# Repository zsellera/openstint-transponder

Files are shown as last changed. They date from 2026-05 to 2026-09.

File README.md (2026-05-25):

# OpenStint transponder reference design, version 2

RC (surface) racing transponder with ATtiny816/1616/3216, featuring:
* OpenStint protocol reference implentation (this is not an RC3 clone!)
* 5 MHz BPSK using SPI MOSI (UART module can send SPI without transmit gaps)
* A two-transistor push-pull coil driver
* Signal level is circa the same as of an RC4
* Works down to 2.8V, output level remains flat down to 3.4V (MiniZ/1S support)
* Reverse polarity protection
* Power line filtering
* LCSC product codes added (orderable from JLCPCB)

**Related projects:** [OpenStint decoder](https://github.com/zsellera/openstint) | [Loop Amplifier](https://github.com/zsellera/openstint-preamp)

JLCPCB manifactures and assembles 5 panels of 2x4s, grand total of 40 pcs, for less than $200, including taxes and shipping (Hungary 27% VAT, no tariff, 2026 May).

openstint transponder v2

**Signal level**

Blue: RC4Hybrid, yellow: OpenStint v2 (antenna is the same distance from the detector)
OpenStint transponder to RC4H comparision

**Radio performance**
SpikeImage0022

## Old version

There is a previous version, with lower output level, more stressed components, pickier power requirements, using an STM32 MCU. It's on [v1](https://github.com/zsellera/openstint-transponder/tree/v1) branch. Production files from [2025 December](https://github.com/zsellera/openstint-transponder/releases/tag/release-2025-12-10).

## Manufacting

See [relases](https://github.com/zsellera/openstint-transponder/releases/tag/nightly-master) for gerber, pos and BOM files. These are directly uploadable to [JLCPCB](https://jlcpcb.com/).

[Order placement guide](https://www.rctech.net/forum/showpost.php?p=16260447&postcount=66)

Order a standard 1.2 mm 4-layer PCB to get the same performace as tested.

```
kikit panelize \
    --layout 'hspace: 3mm; vspace: 3mm; rows: 4; cols: 2' \
    --tabs 'type: fixed; vwidth: 4mm; hwidth: 4mm; vcount: 0' \
    --cuts 'type: mousebites; offset: -0.25mm' \
    --framing 'type: frame; hspace: 3mm; vspace: 3mm; width: 4mm' \
    --post 'millradius: 1.5mm' \
    ...
```

```
kikit fab jlcpcb --assembly --schematic ./openstint-transponder.kicad_sch ./panel/panel-8.kicad_pcb panel/
```

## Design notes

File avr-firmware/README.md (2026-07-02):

# AVR Firmware

Firmware for the OpenStint transponder, targeting the **ATtiny816**/**ATtiny1616**/**ATtiny3216**.

Not tested with 416, but I think it would work there as well. Not measured, but I guesstimate the stack size upper limit to be around 80-90 bytes.

## Precompiled firmware

An automated job compiles the firmware, check out [releases](https://github.com/zsellera/openstint-transponder/releases/tag/nightly-master).

## Prerequisites

- `avr-gcc` toolchain (avr-gcc, avr-objcopy, avr-size)
- `avrdude` for flashing
- **Microchip ATtiny Device Family Pack (DFP)** — required because avr-libc does not ship full support for newer ATtiny 0/1/2-series chips

## Building

The project generates a Makefile with CMake, downloading AVR support packages meanwhile.

```sh
mkdir build
cd build
cmake ..
make
```

Alternatives:

```sh
# v1 revision (led on different pin)
cmake -B build -DHW_REV=v1

# manual DFP path
cmake -B build -DATTINY_DFP=/path/to/Atmel.ATtiny_DFP.2.0.368

# use "adafruit high voltage programmer"
cmake -B build -DPROGRAMMER=serialupdi
```

### Obtaining the ATtiny DFP manually

The new CMake script downloads this automatically

The DFP provides the device-specific headers, linker scripts, and startup objects needed by avr-gcc.

1. Go to the Microchip Packs Repository: <http://packs.download.atmel.com/>
2. Search for **ATtiny** and download the latest **Atmel ATtiny Series Device Support** pack (e.g. `Atmel.ATtiny_DFP.2.0.368.atpack`)
3. The `.atpack` file is a regular ZIP archive — extract it to a directory of your choice:
   ```sh
   unzip Atmel.ATtiny_DFP.2.0.368.atpack -d Atmel.ATtiny_DFP.2.0.368
   ```

The extracted directory structure contains:
```
Atmel.ATtiny_DFP.2.0.368/
  gcc/dev/attiny816/   -- linker scripts and startup objects (-B path)
  gcc/dev/attiny1616/   -- linker scripts and startup objects (-B path)
  include/              -- device header files (-I path)
```

## Flashing

```sh
make flash
```

This uses `avrdude` with an Atmel-ICE programmer over UPDI.

## Fuse Programming

FOR PAST/FUTURE REFERENCE ONLY, THIS STEP IS NOT REQUIRED!

ATtinys have an internal oscillator, which - by default - run at 16 MHz. A fuse programming
is required to make it 20 MHz. However it's pointless - the RC oscillator is so unprecise we can not calibratie it to be within 5 MHz ±19 kHz reliably (which is needed for openstint decoder to detect it).

To set the main oscillator to 20 MHz:

```sh
make fuse
```

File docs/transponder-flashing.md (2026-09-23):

---
title: Flashing OpenStint Transponder Firmware
description: How to flash the ATtiny-based OpenStint RC lap timing transponder firmware using an Atmel-ICE or a cheap UPDI programmer.
---

# Flashing the firmware

There is an automated job that compiles the firmware, check out [releases](https://github.com/zsellera/openstint-transponder/releases/tag/nightly-master). You'll need the `.hex` file. You can [compile yourself](https://github.com/zsellera/openstint-transponder/blob/master/avr-firmware/README.md), of course.

To flash the firmware, I use an [ATMEL-ICE](https://www.microchip.com/en-us/development-tool/atatmel-ice), sourceable from Mouser/DigiKey/etc. (~$100).

A much cheaper alternative is [Adafruit High Voltage UPDI Friend - USB Serial UPDI Programmer](https://www.adafruit.com/product/5893) (~$10).

## Hardware

There are test points on the bottom of the transponder:
* **VDD** powers the LDO, apply 4+ V here
* **VTG** is a testpoint to check the LDO output voltage (should be 3.3V)
* **GND**
* **UPDI** is the programming pin

You can connect +3.3V directly to `VTG`, as the LDO has reverse current protection, and not use `VDD` (leave floating).

The v2 transponder's test point spacing is 2.54 mm / 0.1" away from each other. You need pogo pins to make proper contact. [Adafruit](https://www.adafruit.com/product/5381), [AliExpress](https://www.aliexpress.com/item/4000452882780.html).

## Software

I use [avrdude](https://github.com/avrdudes/avrdude/), the makescript use it as well.

Program both the fuses and the flash memory! The fuses are set to use the 20 MHz internal RC oscillator as a fallback if the crystal oscillator fails, as a fallback mechanism.

This does both:
```
make flash
```

OR:
```
avrdude -c serialupdi -p attiny816 -U "flash:w:main.hex" -U fuse1:w:0x02:m
```

## Reading the transponder ID

The transponder ID is not stored anywhere: the firmware calculates it at boot from the chip's factory serial number (`crc32(SIGROW.SERNUM0..9) % 10000000`). The serial number is readable over UPDI, so [tools/transponder_id.py](https://github.com/zsellera/openstint-transponder/blob/master/tools/transponder_id.py) can tell you the ID a board will transmit, over the same connection you flash with. No decoder or RF power-up needed. It is read-only and works on a blank chip too.

It needs Python 3 and avrdude 7.x or newer (for the `sernum` memory), with a `serialupdi` programmer:

```
$ python tools/transponder_id.py --port COM5
SERNUM : 2F510C111E4277A305BB
ID     : 4729780
```

When building a batch, add `--csv` and `--label` to collect a labelling list as you go. Each run appends a `timestamp;label;sernum;transponder_id` row:

```
python tools/transponder_id.py --port COM5 --csv transponders.csv --label 07
```

Run `python tools/transponder_id.py --help` for the rest of the options (`--baud`, `--part`, `--avrdude`).

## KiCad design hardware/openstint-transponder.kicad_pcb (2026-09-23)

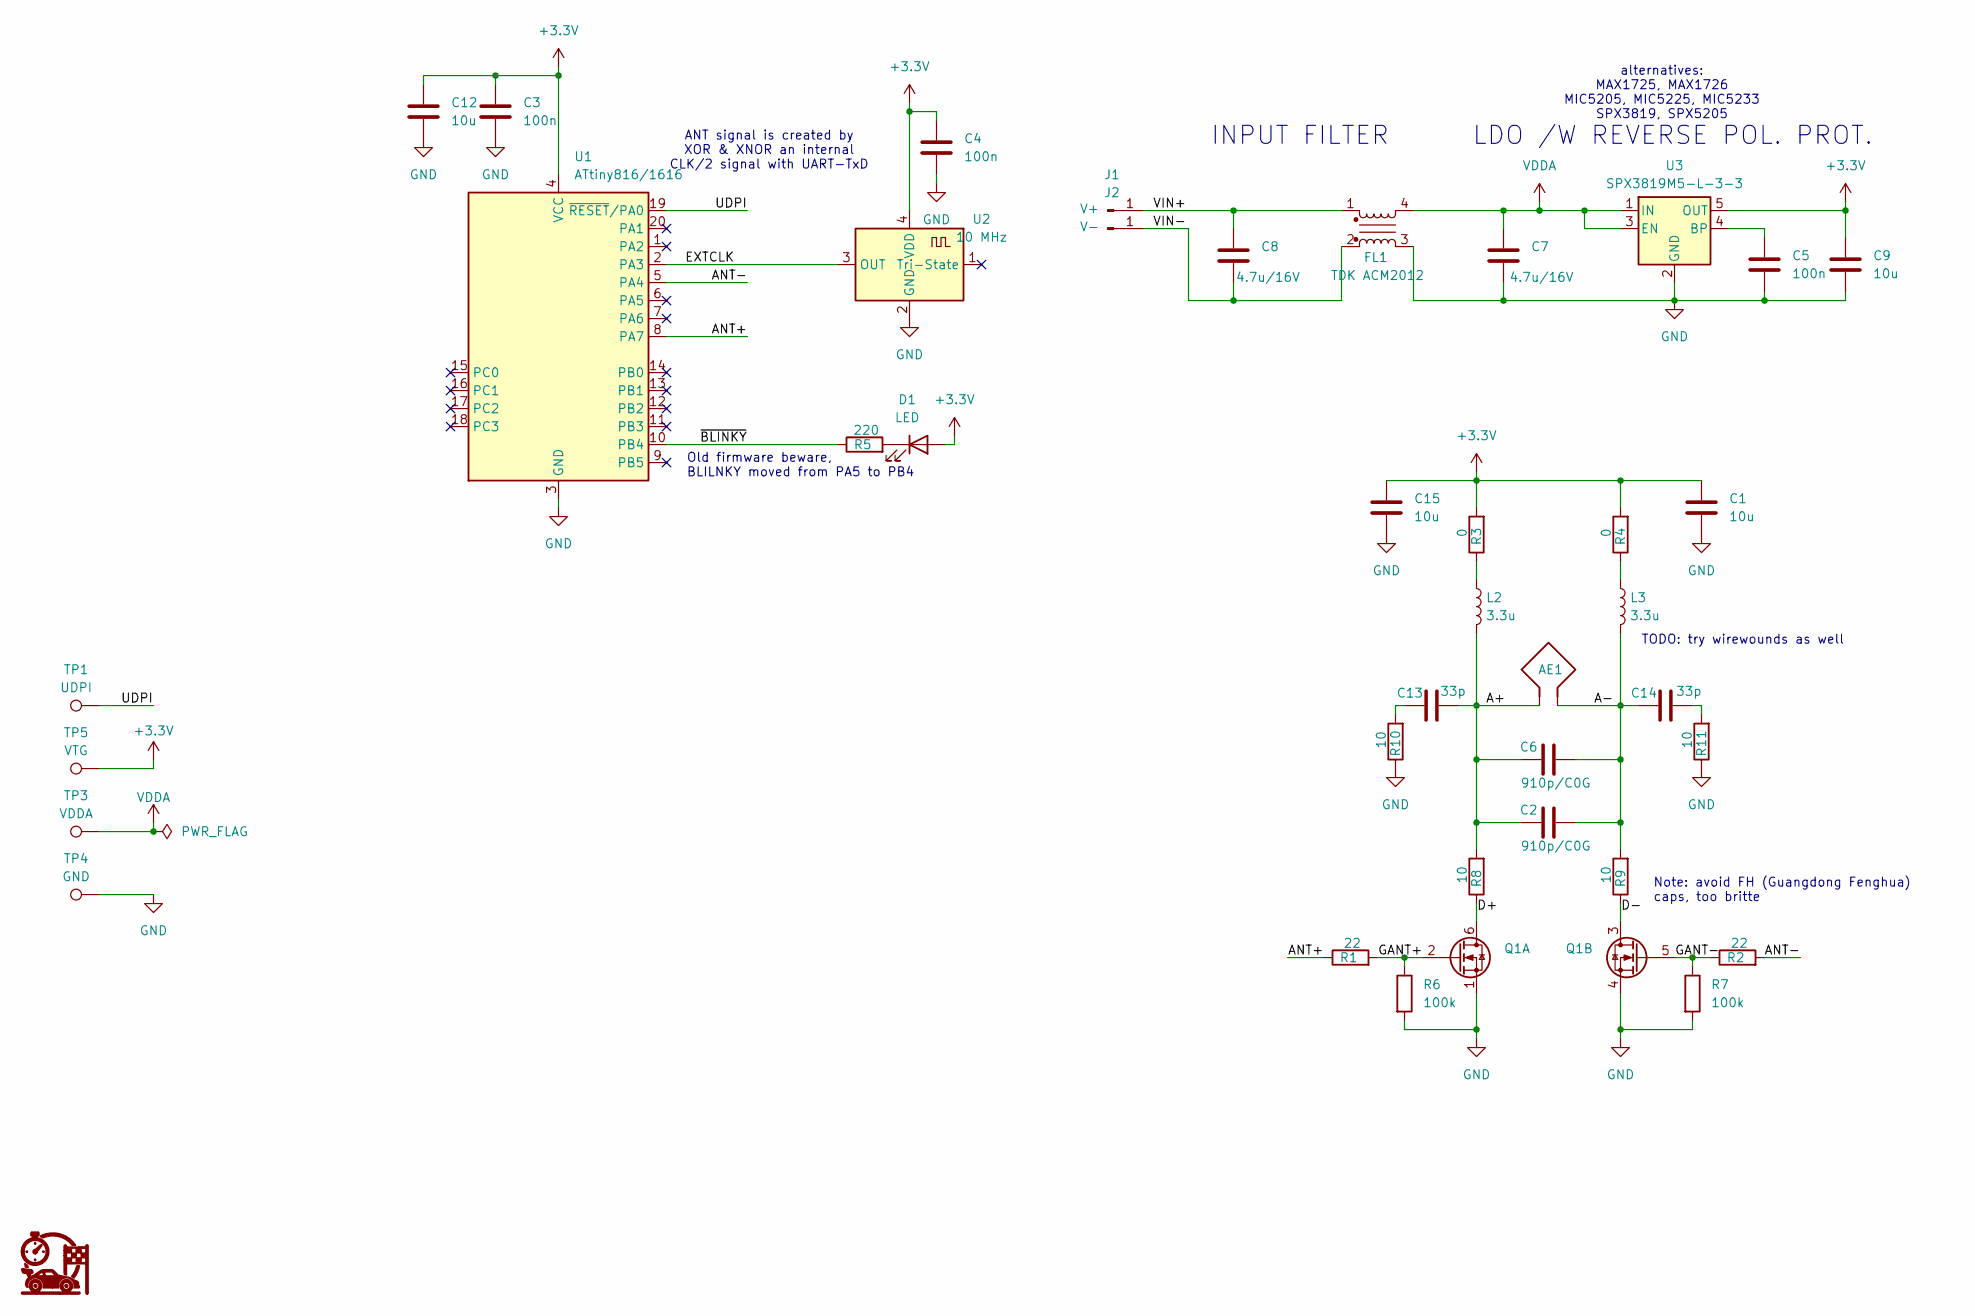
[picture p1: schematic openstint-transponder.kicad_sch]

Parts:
AE1: Antenna_Loop
C1, C9, C12, C15: 10u; C_0402_1005Metric; LCSC C15525
C2, C6: 910p/C0G; C_0402_1005Metric; LCSC C2941944
C3, C4, C5: 100n; C_0402_1005Metric; LCSC C1525
C7, C8: 4.7u/16V; C_0603_1608Metric; LCSC C19666
C13, C14: 33p; C_0402_1005Metric; LCSC C1562
D1: LED; LED_0603_1608Metric; LCSC C2286
FL1: TDK ACM2012; ACM2012; LCSC C76571
G1: SYM_OpenStint; openstint-logo_12x12
J1: V+; SolderWirePad_1x01_SMD_1x2mm
J2: V-; SolderWirePad_1x01_SMD_1x2mm
L2, L3: 3.3u; L_0603_1608Metric; LCSC C162581
Q1: PMGD280UN; SOT-363_SC-70-6; LCSC C135817
R1, R2: 22; R_0402_1005Metric; LCSC C25092
R3, R4: 0; R_0402_1005Metric; LCSC C17168
R5: 220; R_0402_1005Metric; LCSC C25091
R6, R7: 100k; R_0402_1005Metric; LCSC C25741
R8, R9, R10, R11: 10; R_0402_1005Metric; LCSC C25077
TP1: UDPI; TestPoint_Pad_D1.0mm
TP3: VDDA; TestPoint_Pad_D1.0mm
TP4: GND; TestPoint_Pad_D1.0mm
TP5: VTG; TestPoint_Pad_D1.0mm
U1: ATtiny816/1616; VQFN-20-1EP_3x3mm_P0.4mm_EP1.7x1.7mm; LCSC C2052778
U2: 10 MHz; Crystal_SMD_3225-4Pin_3.2x2.5mm; LCSC C2831380
U3: SPX3819M5-L-3-3; SOT-23-5; LCSC C9055

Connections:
+3.3V: C1.1, C3.2, C4.2, C9.1, C12.1, C15.1, D1.2 (A), R3.2, R4.2, TP5.1, U1.4 (VCC), U2.4 (VDD), U3.5 (OUT)
/A+: AE1.1, C2.1, C6.1, C13.2, L2.2, R8.2
/A-: AE1.2, C2.2, C6.2, C14.1, L3.2, R9.2
/ANT+: R1.1, U1.8 (PA7)
/ANT-: R2.2, U1.5 (PA4)
/D+: Q1.6 (D), R8.1
/D-: Q1.3 (D), R9.1
/EXTCLK: U1.2 (PA3), U2.3 (OUT)
/GANT+: Q1.2 (G), R1.2, R6.1
/GANT-: Q1.5 (G), R2.1, R7.1
/UDPI: TP1.1, U1.19 (~RESET/PA0)
/VIN+: C8.1, FL1.1, J1.1
/VIN-: C8.2, FL1.2, J2.1
/~BLINKY: R5.1, U1.10 (PB4)
GND: C1.2, C3.1, C4.1, C5.2, C7.2, C9.2, C12.2, C15.2, FL1.3, Q1.1 (S), Q1.4 (S), R6.2, R7.2, R10.1, R11.1, TP4.1, U1.3 (GND), U1.21 (GND), U2.2 (GND), U3.2 (GND)
unnamed: C13.1, R10.2
unnamed: C14.2, R11.2
unnamed: D1.1 (K), R5.2
unnamed: L2.1, R3.1
unnamed: L3.1, R4.1
unnamed: C5.1, U3.4 (BP)
VDDA: C7.1, FL1.4, TP3.1, U3.1 (IN), U3.3 (EN)

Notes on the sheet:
Note: avoid FH (Guangdong Fenghua) caps, too britte
Old firmware beware, BLILNKY moved from PA5 to PB4
TODO: try wirewounds as well
alternatives: MAX1725, MAX1726 MIC5205, MIC5225, MIC5233 SPX3819, SPX5205
INPUT FILTER
ANT signal is created by XOR & XNOR an internal CLK/2 signal with UART-TxD
LDO /W REVERSE POL. PROT.

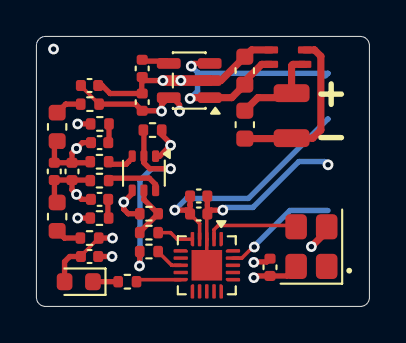
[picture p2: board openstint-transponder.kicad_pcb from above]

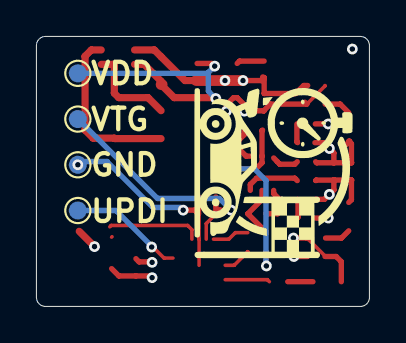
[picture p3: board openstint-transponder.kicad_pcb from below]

Board: 4 copper layers, 18.5 x 15.0 mm, 39 parts (5 on the bottom side), 22 nets.

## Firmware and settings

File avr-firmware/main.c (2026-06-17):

#define F_CPU 10000000UL  // Match your external CMOS clock frequency

#include <avr/io.h>
#include <avr/interrupt.h>
#include <avr/cpufunc.h>
#include <avr/fuse.h>
#include <avr/sleep.h>
#include <avr/wdt.h>

#include <stddef.h>
#include <stdbool.h>
#include <string.h>

FUSES = {
    .OSCCFG = 0x2,  // 0x02 = 20 MHz
};

#define FRAME_LEN 12

#ifndef LED_PORT
#define LED_PORT    (PORTB)
#endif
#ifndef LED_PIN_bm
#define LED_PIN_bm  PIN4_bm
#endif

#define	V29POLYA	0x1af
#define	V29POLYB	0x11d

uint32_t crc32_update(uint32_t crc, uint8_t data)
{
    crc ^= data;
    for (int i = 0; i < 8; i++)
        crc = (crc >> 1) ^ (0xEDB88320U & (-(int)(crc & 1)));
    return crc;
}

uint32_t crc32_calc(const void *data, size_t len)
{
    uint32_t crc = 0xFFFFFFFF;
    const uint8_t *p = (const uint8_t *)data;
    while (len--)
        crc = crc32_update(crc, *p++);
    return ~crc;
}

uint8_t crc8_generate_key(uint8_t *_msg, size_t len)
{
    uint32_t i, j, b, mask, key8=~0, poly = 0xe0;
    for (i=0; i<len; i++) {
        b = _msg[i];
        key8 ^= b;
        for (j=0; j<8; j++) {
            mask = -(key8 & 1);
            key8 = (key8>>1) ^ (poly & mask);
        }
    }
    return (~key8) & 0xff;
}

static inline uint8_t parity32(uint32_t x)
{
    x ^= x >> 16;
    x ^= x >> 8;
    x ^= x >> 4;
    x &= 0xF;
    x = (0x6996 >> x) & 1;
    return (uint8_t) x;
}

void encode_transponder_msg(uint8_t* dst, uint8_t msg[4]) {
    // this function requires a zeroed buffer
    memset(dst, 0, 10);

    // init with zeroed register (convention)
	uint32_t shreg = 0;
    // conv encode:
    for (int k=0; k<4; k++) {
        for (int i=0; i<4; ++i) {
            // append bit to shift register
            int msg_bit = (msg[k] >> (7-i)) & 1;
            shreg <<= 1;
            shreg |= msg_bit;
            uint8_t x = (parity32(shreg & V29POLYA) << 1) | parity32(shreg & V29POLYB);
            dst[2*k] |= (x << (3-i)*2);
        }
        for (int i=4; i<8; ++i) {
            // append bit to shift register
            int msg_bit = (msg[k] >> (7-i)) & 1;
            shreg <<= 1;
            shreg |= msg_bit;
            uint8_t x = (parity32(shreg & V29POLYA) << 1) | parity32(shreg & V29POLYB);
            dst[2*k+1] |= (x << (7-i)*2);
        }
    }
	// trailing 0x00
	for (int i=0; i<4; ++i) {
		// shift in a zero
		shreg <<= 1;
		shreg &= 0xffe;
		uint8_t x = (parity32(shreg & V29POLYA) << 1) | parity32(shreg & V29POLYB);
        dst[8] |= (x << (3-i)*2);
	}
    for (int i=4; i<8; ++i) {
		// shift in a zero
		shreg <<= 1;
		shreg &= 0xffe;
		uint8_t x = (parity32(shreg & V29POLYA) << 1) | parity32(shreg & V29POLYB);
        dst[9] |= (x << (7-i)*2);
	}
}

void encode_payload(uint8_t* dst, uint32_t payload24) {
    // create transponder message (id + crc8):
    uint8_t message[4];
    message[0] = (uint8_t)((payload24 >> 16) & 0xFF);
    message[1] = (uint8_t)((payload24 >> 8) & 0xFF);
    message[2] = (uint8_t)(payload24 & 0xFF);
    message[3] = crc8_generate_key(message, 3);

    // convolutional encoder:
    encode_transponder_msg(dst, message);
}

// ticks are read-write from interrupt; as it's 32-bit,
// read-write takes multiple cycles.
static volatile uint32_t _ticks;  // 10 kHz free-running counter (100 us per tick)
static uint32_t ticks_read(void)
{
    cli(); // do not increment tick while reading
    uint32_t t = _ticks;
    sei();
    return t;
}

ISR(TCB0_INT_vect) {
    _ticks++;
    TCB0.INTFLAGS = TCB_CAPT_bm;
}

// true once the external CMOS clock is running; false if we fell back
// to the internal RC oscillator. Gates timesync transmission and the
// LED blink pattern.
static volatile bool precise_clock = false;

static uint16_t lfsr = 0xACE1;

static uint8_t rand8(void)
{
    uint16_t bit = ((lfsr >> 0) ^ (lfsr >> 2) ^ (lfsr >> 3) ^ (lfsr >> 5)) & 1;
    lfsr = (lfsr >> 1) | (bit << 15);
    return (uint8_t)lfsr;
}

void handle_led(uint16_t cntr) {
    switch (cntr) {
        case 0:  LED_PORT.OUTCLR = LED_PIN_bm; break; // on  (blink 1)
        case 17: LED_PORT.OUTSET = LED_PIN_bm; break; // off
        case 34: if (!precise_clock) { LED_PORT.OUTCLR = LED_PIN_bm; } break; // on  (blink 2)
        case 51: LED_PORT.OUTSET = LED_PIN_bm; break; // off
    }
}

void transmit_frame(const uint8_t *frame)
{
    const uint8_t *fp = frame;
    cli();
    __asm__ __volatile__ (
        // Init sequence: 4 symbols @ 1.25 MHz = 3.2 us = 32 cycles
        // SPI idle is active-high, we must send 0x00, and time it so
        // only last 4 bits are output to CCL pins
        "ldi r16, 0              \n\t"  // prime
        "sts %[txdata], r16      \n\t"  // starts shifting; DREIF will set
        // tuned wait loop
        "ldi r16, 10             \n\t"  // ca. 17 peaks in sent data
    "1:                          \n\t"
        "dec r16                 \n\t"
        "brne 1b                 \n\t"
        // waint complete, enable CCL
        "lds r16, %[cclctrla]    \n\t"  // 3 cyc
        "ori r16, %[cclen]       \n\t"  // 1 cyc
        "sts %[cclctrla], r16    \n\t"  // 2 cyc
        // prepare transmit:
        "ldi r18, %[len]         \n\t" 

        // Transmit frame bytes
    "2:                          \n\t"
        "lds r16, %[status]      \n\t"  // 3 cyc - USART0.STATUS
        "sbrs r16, 5             \n\t"  // 1/2 cyc - skip if DREIF set
        "rjmp 2b                 \n\t"  // 2 cyc
        "ld r17, Z+              \n\t"  // 2 cyc - frame[i++]
        "sts %[txdata], r17      \n\t"  // 2 cyc - USART0.TXDATAL
        "dec r18                 \n\t"  // 1 cyc
        "brne 2b                 \n\t"  // 2/1 cyc

        // Wait for TX complete
    "3:                          \n\t"
        "lds r16, %[status]      \n\t"  // USART0.STATUS
        "sbrs r16, 6             \n\t"  // skip if TXCIF set
        "rjmp 3b                 \n\t"
        "ldi r16, %[txcif]       \n\t"
        "sts %[status], r16      \n\t"  // clear TXCIF

        // Tail sequence: ~4 symbols @ 1.25 MHz = 32 cycles
        // CCL still enabled, carrier runs as unmodulated tail
        // Overhead to CCL disable: lds (3) + andi (1) + sts (2) = 6 cyc
        // Budget: 32 - 6 = 26 cyc => ldi (1) + loop 3*9-1 = 26 => N=9
        "ldi r16, 9              \n\t"  // 1 cyc
    "4:                          \n\t"
        "dec r16                 \n\t"  // 1 cyc
        "brne 4b                 \n\t"  // 2 taken / 1 not taken

        // Disable CCL
        "lds r16, %[cclctrla]    \n\t"
        "andi r16, %[ccldis]     \n\t"
        "sts %[cclctrla], r16    \n\t"

        : "+z" (fp)
        : [status]   "i" (&USART0.STATUS),
          [txdata]   "i" (&USART0.TXDATAL),
          [cclctrla] "i" (&CCL.CTRLA),
          [txcif]    "M" (USART_TXCIF_bm),
          [len]      "M" (FRAME_LEN),
          [cclen]    "M" (CCL_ENABLE_bm),
          [ccldis]   "n" (~CCL_ENABLE_bm)
        : "r16", "r17", "r18", "memory"
    );
    sei();
}

int main(void)
{
    // PB4 LED — one small blink when timecode it sent
    LED_PORT.DIRSET = LED_PIN_bm;
    LED_PORT.OUTCLR = LED_PIN_bm; // led off

    // External CMOS clock on CLKI pin; update F_CPU to match your clock source
    ccp_write_io((void *)&CLKCTRL.MCLKCTRLA, CLKCTRL_CLKSEL_EXTCLK_gc);

    // Wait up to ~100 ms for the external clock to actually start
    // Until the external clock starts the CPU runs on OSC20M,
    // prescaled = 20 MHz / 6 = 3.333 MHz
    uint32_t clk_timeout = 33333UL; // ca. 100 ms
    while (!(CLKCTRL.MCLKSTATUS & CLKCTRL_EXTS_bm)) {
        if (--clk_timeout == 0)
            break;
    }

    if (CLKCTRL.MCLKSTATUS & CLKCTRL_EXTS_bm) {
        ccp_write_io((void *)&CLKCTRL.MCLKCTRLB, 0);  // No prescaler
        precise_clock = true;  // external clock confirmed running
    } else {
        // External clock never started: fall back to the internal
        // 20 MHz RC oscillator with /2 prescaler = 10 MHz (keeps F_CPU).
        ccp_write_io((void *)&CLKCTRL.MCLKCTRLA, CLKCTRL_CLKSEL_OSC20M_gc);
        ccp_write_io((void *)&CLKCTRL.MCLKCTRLB, CLKCTRL_PDIV_2X_gc | CLKCTRL_PEN_bm);
        precise_clock = false;
    }

    LED_PORT.OUTSET = LED_PIN_bm; // led off (resting state)

    // setup timer for a 10 kHz internal tick
    TCB0.CCMP    = 499;   // 10 MHz / 2 / (499+1) = 10 kHz
    TCB0.CTRLA   = TCB_CLKSEL_CLKDIV2_gc | TCB_ENABLE_bm;
    TCB0.INTCTRL = TCB_CAPT_bm;

    // enable sleep mode, peripherals remain active:
    SLPCTRL.CTRLA = SLPCTRL_SMODE_IDLE_gc | SLPCTRL_SEN_bm;
    sei();

    // UART in Master SPI Mode
    PORTB.DIRSET |= PIN2_bm | PIN1_bm;  // TXD (MOSI) and XCK (SCK) as outputs
    USART0.BAUD = 256;                  // Max baud rate: F_CPU / 2 = 5 MHz
    USART0.CTRLC = USART_CMODE_MSPI_gc | USART_CHSIZE_8BIT_gc;
    USART0.CTRLB = USART_TXEN_bm;

    // TCA (timer generate 5 MHz square, this gets modulated by CCL)
    PORTB.DIRSET |= PIN0_bm;
    TCA0.SINGLE.CTRLA = TCA_SINGLE_CLKSEL_DIV1_gc;
    TCA0.SINGLE.CTRLB = TCA_SINGLE_WGMODE_FRQ_gc
                      | TCA_SINGLE_CMP0EN_bm;
    TCA0.SINGLE.CMP0 = 0;
    TCA0.SINGLE.CTRLA |= TCA_SINGLE_ENABLE_bm;

    // Configurable Custom Logic (modulate: SPI_MOSI ^ TCA)
    PORTA.DIRSET |= PIN4_bm | PIN7_bm; // Configure LUT output pins as outputs
    CCL.CTRLA &= ~CCL_ENABLE_bm; // Make sure CCL is disabled before touching LUT registers
    // LUT0: MOSI ^ TCA
    CCL.LUT0CTRLB = CCL_INSEL1_USART0_gc | CCL_INSEL0_TCA0_gc;
    CCL.LUT0CTRLC = CCL_INSEL2_MASK_gc;
    CCL.TRUTH0 = 0x99;
    CCL.LUT0CTRLA = CCL_OUTEN_bm | CCL_ENABLE_bm | CCL_FILTSEL_SYNCH_gc;
    // LUT1: ~(MOSI ^ TCA)
    CCL.LUT1CTRLB = CCL_INSEL1_USART0_gc | CCL_INSEL0_TCA0_gc;
    CCL.LUT1CTRLC = CCL_INSEL2_MASK_gc;
    CCL.TRUTH1 = 0x66;
    CCL.LUT1CTRLA = CCL_OUTEN_bm | CCL_ENABLE_bm | CCL_FILTSEL_SYNCH_gc;
    
    // setup transponder id:
    uint8_t id[10] = {
        SIGROW.SERNUM0, SIGROW.SERNUM1, SIGROW.SERNUM2,
        SIGROW.SERNUM3, SIGROW.SERNUM4, SIGROW.SERNUM5,
        SIGROW.SERNUM6, SIGROW.SERNUM7, SIGROW.SERNUM8,
        SIGROW.SERNUM9
    };
    uint32_t transponder_id = crc32_calc(id, sizeof(id)) % 10000000U;

    // construct transponder frame (preamble + encoded payload)
    uint8_t transponder_frame[12] = {0};
    transponder_frame[0] = 0xf9;
    transponder_frame[1] = 0xa8;
    encode_payload(transponder_frame + 2, transponder_id);

    // timesync frame; payload will be encoded later
    uint8_t timesync_frame[12];
    timesync_frame[0] = 0xf9;
    timesync_frame[1] = 0xa8;

    // Watchdog: if the main clock dies at runtime the CPU halts and stops
    // petting the dog. The WDT runs on the independent ULP 32 kHz osc, so
    // it still fires and resets the chip — reboot then takes the startup
    // fallback path (internal RC, precise_clock = false). 0.256 s timeout
    while (WDT.STATUS & WDT_SYNCBUSY_bm);
    ccp_write_io((void *)&WDT.CTRLA, WDT_PERIOD_256CLK_gc);

    uint16_t message_counter = 0;
    uint8_t *tx_frame = transponder_frame; // timesync vs transponder frame
    while (1)
    {
        transmit_frame(tx_frame);

        // Wait 0.8..2.2 ms (avg 1.5 ms, ±700 us jitter)
        // 8 + rand8()%15 ticks at 10 kHz = 0.8-2.2 ms
        uint32_t deadline = ticks_read() + 8 + (rand8() % 15);

        // Count messages. Every 667th message is timecode
        message_counter = (message_counter + 1) % 667;

        // Precise clock: send timesync regularly, blink once per cycle.
        if (precise_clock && message_counter == 0) { // next is the timesync
            // construct timecode message
            // deadline is actually the timecode when the next message is due
            uint32_t timecode = (deadline & 0x000fffff) | 0x00a00000;
            encode_payload(timesync_frame + 2, timecode);

            // re-wire tx_frame
            tx_frame = timesync_frame;
        } else {
            tx_frame = transponder_frame;
        }

        // blink led
        handle_led(message_counter);
        
        while (ticks_read() < deadline) {
            sleep_cpu();
        }
        wdt_reset();
    }
}

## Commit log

2025-12-10 antenna re-tuned
    [openstint-transponder.kicad_pcb, openstint-transponder.kicad_sch]
2025-12-10 readme update
    [openstint-transponder.kicad_sch]
2026-03-11 v2 transponder
    [openstint-transponder.kicad_pcb, openstint-transponder.kicad_sch]
2026-03-23 v2 transponder - initial commit
    [openstint-transponder.kicad_pcb, openstint-transponder.kicad_sch]
2026-04-17 spin v2
    [openstint-transponder.kicad_pcb, openstint-transponder.kicad_sch]
2026-04-19 use 2x tuning caps
    [openstint-transponder.kicad_pcb, openstint-transponder.kicad_sch]
2026-04-19 fine-tune snubber values
    [openstint-transponder.kicad_sch]
2026-05-20 remove old stm32 firmware
2026-06-16 switch to internal 20 MHz on CMOS clock failure
    [main.c]
2026-09-23 transponder b.silkscreen: updi corrected (close #1)
    [openstint-transponder.kicad_pcb]
